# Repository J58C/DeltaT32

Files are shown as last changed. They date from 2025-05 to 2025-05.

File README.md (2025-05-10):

# DeltaT32 – ESP32-C3 Wearable for Capstone



**DeltaT32** is a modular hardware design project based on the **ESP32-C3 Mini-1**, intended primarily for wearable systems, but versatile enough for general-purpose embedded applications. Created using **KiCad 8**, this project includes a main ESP unit and two detachable sensor boards (BMI160/270 and MPU9250), making it ideal for both academic and practical applications.

This design has been created specifically to fulfill the requirements of a **Capstone Project**, integrating modern hardware design practices with real-world applications. Although firmware development is still pending, the hardware is designed to be compatible with the **[esp-rs (ESP32 Rust)](https://github.com/esp-rs)** ecosystem.

## Project Structure

```
DeltaT32/
├── Schematic/ # PDF-format schematics
├── Hardwares/
│ ├── esp-unit-c3-v3/ # KiCad project for the main ESP32-C3 board
│ ├── sensor-bmi-v2/ # KiCad project for the BMI160/270 sensor board
│ └── sensor-mpu-v2/ # KiCad project for the MPU9250 sensor board
├── 3DModels/ # 3D models of components (if available)
├── Archives/ # Archived ZIP files of older versions
├── Materials/ # Bill of Materials (BOM) for each board
└── README.md # Project documentation
````

## Technical Specifications

| Component | Description |
|---|---|
| MCU | ESP32-C3 Mini-1 |
| Sensors | BMI160/270, MPU9250 (modular and detachable) |
| Design Style | Modular: separate mainboard and sensor units |
| CAD Tool | KiCad 8 |
| Firmware | Not included (hardware only) |
| Rust Support | Designed with esp-rs compatibility in mind |
| Outputs | Schematics, BOMs, 3D Visuals |

## Firmware Compatibility

This hardware is designed to be compatible with the **[esp-rs (Rust for ESP32)](https://github.com/esp-rs)** ecosystem, but **no actual firmware has been implemented or tested** using Rust at this time. Custom firmware development in C, C++, or Rust.

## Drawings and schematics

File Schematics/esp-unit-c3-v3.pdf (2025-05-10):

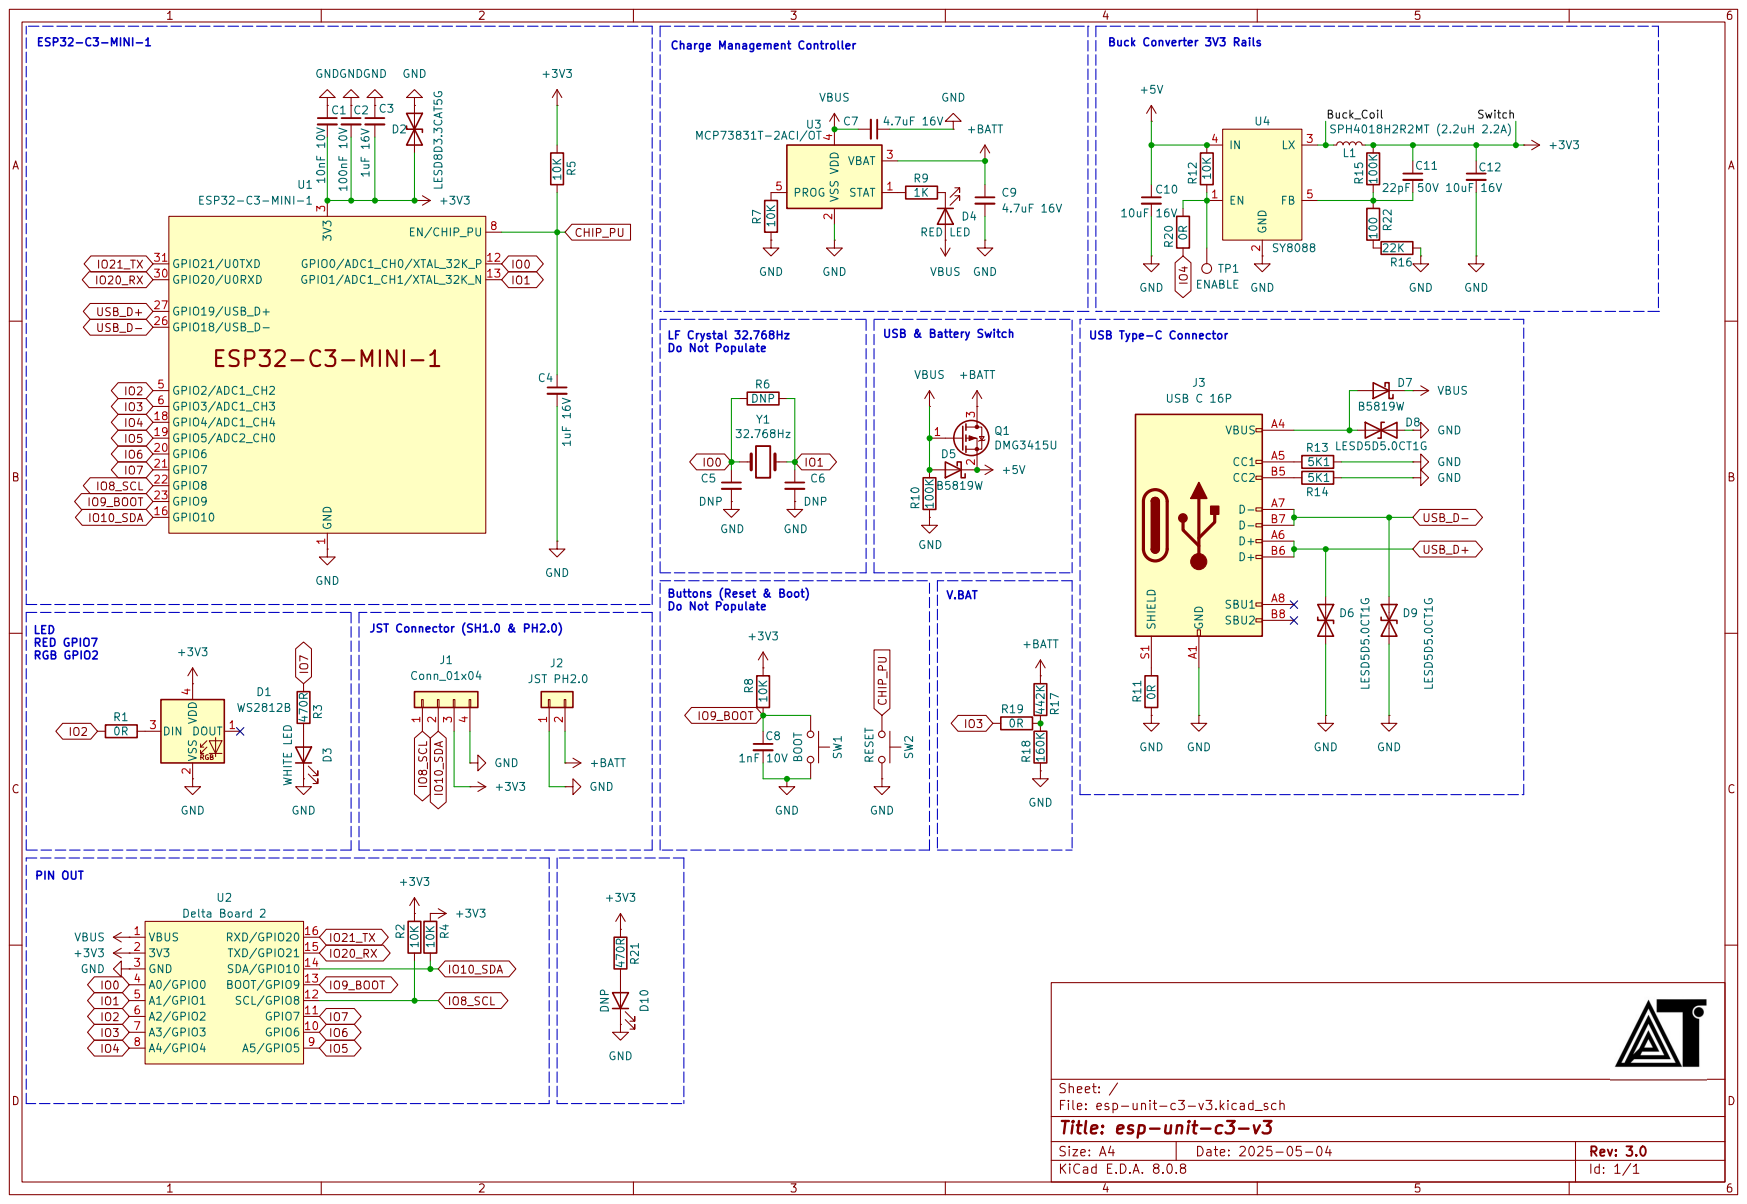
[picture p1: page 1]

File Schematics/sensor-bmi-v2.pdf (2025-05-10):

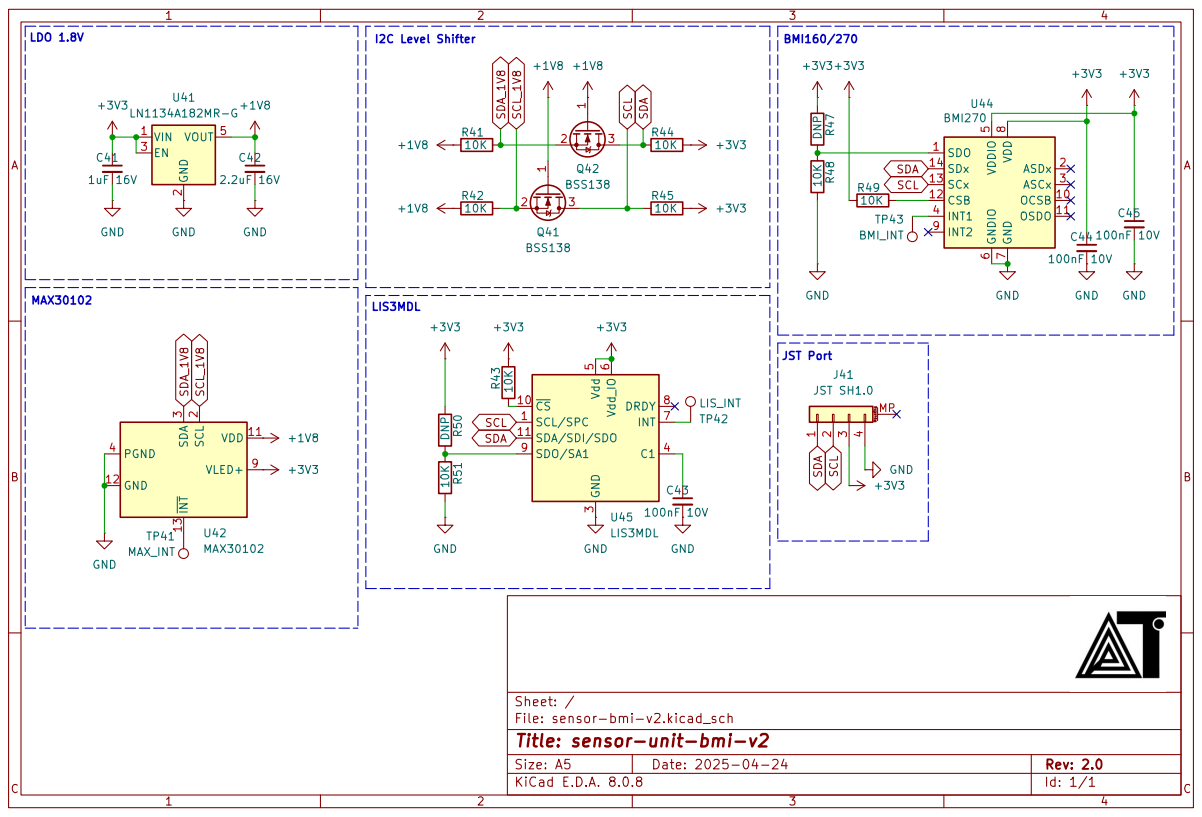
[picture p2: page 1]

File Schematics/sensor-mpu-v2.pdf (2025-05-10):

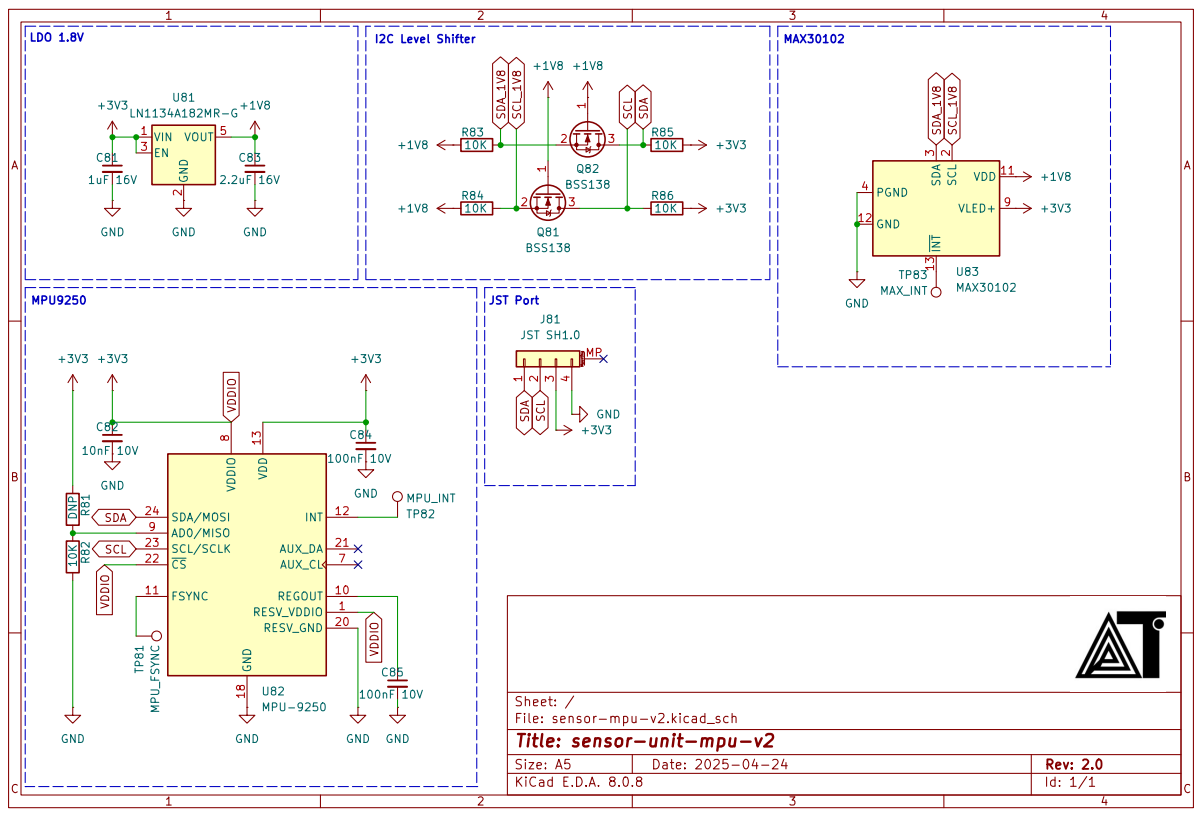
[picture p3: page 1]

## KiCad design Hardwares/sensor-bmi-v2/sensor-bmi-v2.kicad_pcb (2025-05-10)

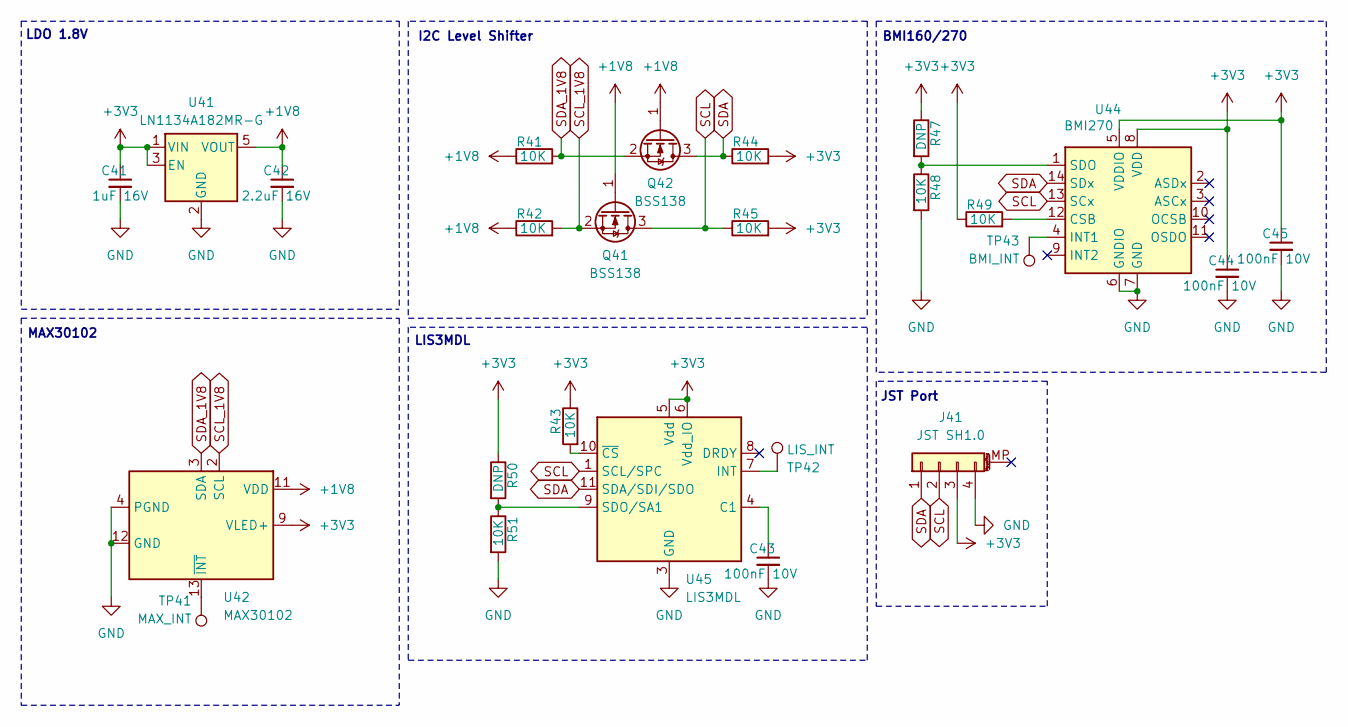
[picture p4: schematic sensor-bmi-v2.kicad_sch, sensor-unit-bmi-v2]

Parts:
C41: 1uF 16V; C_0603_1608Metric; LCSC C15849
C42: 2.2uF 16V; C_0603_1608Metric; LCSC C23630
C43: 100nF 10V; C_0603_1608Metric; LCSC C25744
C44, C45: 100nF 10V; C_0603_1608Metric; LCSC C14663
J41: JST SH1.0; JST_SH_BM04B-SRSS-TB_1x04-1MP_P1.00mm_Vertical
Q41, Q42: BSS138; SOT-23; LCSC C52895
R41, R42, R43, R44, R45, R48, R49, R51: 10K; R_0402_1005Metric; LCSC C25744
R47, R50: DNP; R_0402_1005Metric
TP41: MAX_INT; TestPoint_Pad_D1.0mm
TP42: LIS_INT; TestPoint_Pad_D1.0mm
TP43: BMI_INT; TestPoint_Pad_D1.0mm
U41: LN1134A182MR-G; SOT-23-5; LCSC C141424
U42: MAX30102; Maxim_OLGA-14_3.3x5.6mm_P0.8mm
U44: BMI270; Bosch_LGA-14_3x2.5mm_P0.5mm; LCSC C2836813
U45: LIS3MDL; LGA-12_2x2mm_P0.5mm

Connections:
+1V8: C42.1, Q41.1 (G), Q42.1 (G), R41.1, R42.1, U41.5 (VOUT), U42.11 (VDD)
+3V3: C41.1, C44.1, C45.1, J41.3, R43.1, R44.2, R45.2, R47.1, R49.1, R50.1, U41.1 (VIN), U41.3 (EN), U42.9 (VLED+), U42.10 (VLED+), U44.5 (VDDIO), U44.8 (VDD), U45.5 (Vdd), U45.6 (Vdd_IO)
GND: C41.2, C42.2, C43.2, C44.2, C45.2, J41.4, R48.2, R51.2, U41.2 (GND), U42.4 (PGND), U42.12 (GND), U44.6 (GNDIO), U44.7 (GND), U45.2 (GND), U45.3 (GND), U45.12 (GND)
unnamed: TP41.1, U42.13 (~INT)
unnamed: R49.2, U44.12 (CSB)
unnamed: TP43.1, U44.4 (INT1)
unnamed: R47.2, R48.1, U44.1 (SDO)
unnamed: C43.1, U45.4 (C1)
unnamed: TP42.1, U45.7 (INT)
unnamed: R50.2, R51.1, U45.9 (SDO/SA1)
unnamed: R43.2, U45.10 (~CS)
SCL: J41.2, Q41.3 (D), R45.1, U44.13 (SCx), U45.1 (SCL/SPC)
SCL_1V8: Q41.2 (S), R42.2, U42.2 (SCL)
SDA: J41.1, Q42.3 (D), R44.1, U44.14 (SDx), U45.11 (SDA/SDI/SDO)
SDA_1V8: Q42.2 (S), R41.2, U42.3 (SDA)

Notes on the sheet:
LDO 1.8V
MAX30102
JST Port
LIS3MDL
BMI160/270
I2C Level Shifter

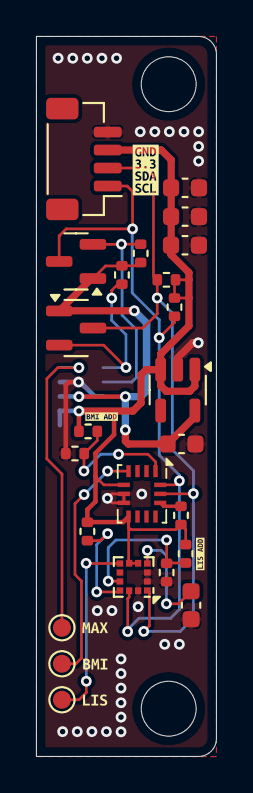
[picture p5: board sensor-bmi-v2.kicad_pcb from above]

Board: 2 copper layers, 10.0 x 40.0 mm, 31 parts (1 on the bottom side), 15 nets.

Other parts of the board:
kibuzzard-680F6A2F: G***; kibuzzard-680F6A2F
kibuzzard-680F6A44: G***; kibuzzard-680F6A44
kibuzzard-680F69F9: G***; kibuzzard-680F69F9
kibuzzard-6818BCEF: G***; kibuzzard-6818BCEF
kibuzzard-6818BD0F: G***; kibuzzard-6818BD0F
kibuzzard-6817376F: G***; kibuzzard-6817376F

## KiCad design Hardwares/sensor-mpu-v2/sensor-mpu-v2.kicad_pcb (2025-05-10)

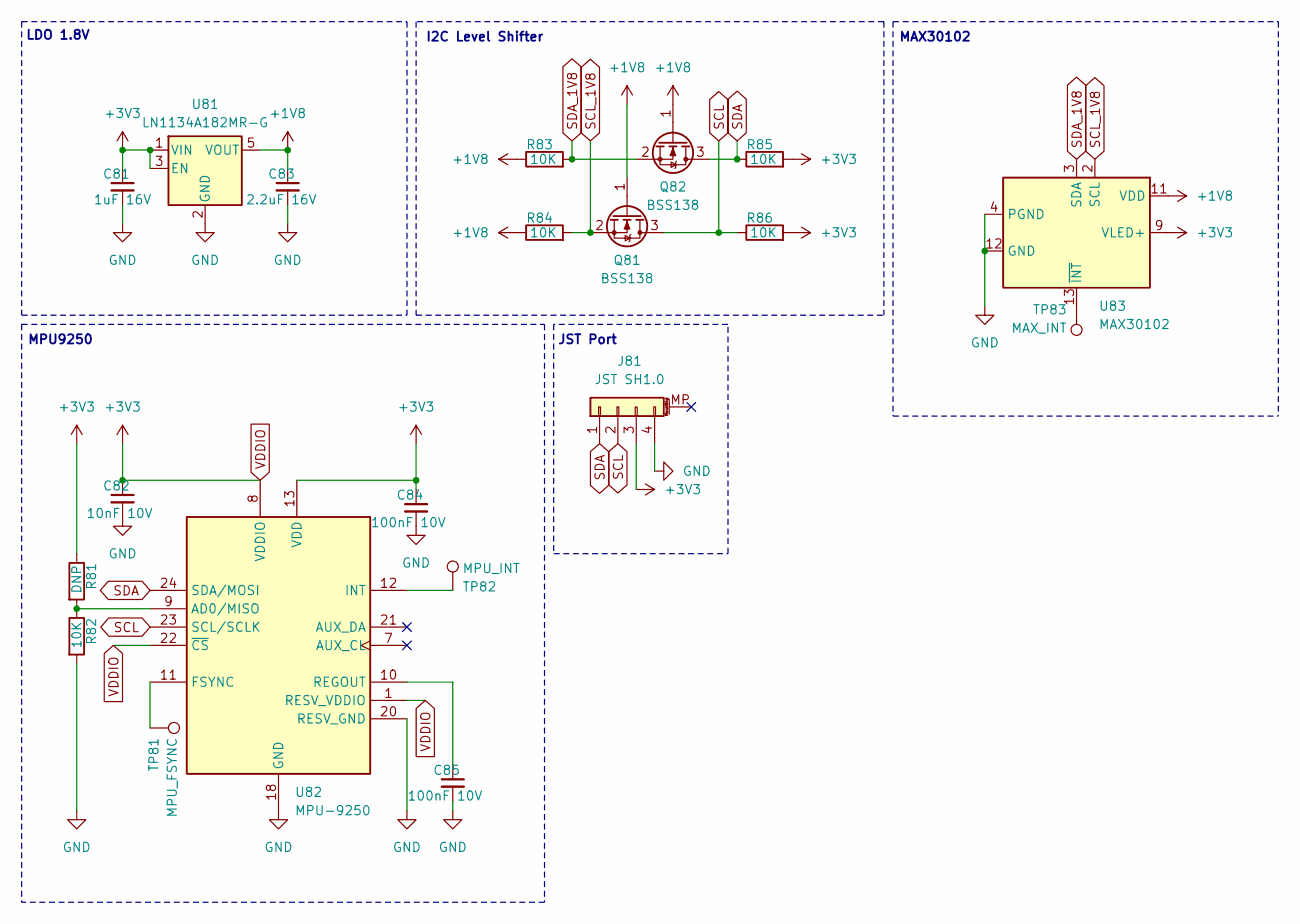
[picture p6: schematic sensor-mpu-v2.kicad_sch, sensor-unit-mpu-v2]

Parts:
C81: 1uF 16V; C_0603_1608Metric; LCSC C52923
C82: 10nF 10V; C_0603_1608Metric; LCSC C15195
C83: 2.2uF 16V; C_0603_1608Metric; LCSC C23630
C84, C85: 100nF 10V; C_0603_1608Metric; LCSC C1525
J81: JST SH1.0; JST_SH_BM04B-SRSS-TB_1x04-1MP_P1.00mm_Vertical
Q81, Q82: BSS138; SOT-23; LCSC C52895
R81: DNP; R_0402_1005Metric
R82, R83, R84, R85, R86: 10K; R_0402_1005Metric; LCSC C25744
TP81: MPU_FSYNC; TestPoint_Pad_D1.0mm
TP82: MPU_INT; TestPoint_Pad_D1.0mm
TP83: MAX_INT; TestPoint_Pad_D1.0mm
U81: LN1134A182MR-G; SOT-23-5; LCSC C141424
U82: MPU-9250; InvenSense_QFN-24_3x3mm_P0.4mm_NoMask
U83: MAX30102; Maxim_OLGA-14_3.3x5.6mm_P0.8mm

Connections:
+1V8: C83.1, Q81.1 (G), Q82.1 (G), R83.1, R84.1, U81.5 (VOUT), U83.11 (VDD)
GND: C81.2, C82.2, C83.2, C84.2, C85.2, J81.4, R82.2, U81.2 (GND), U82.18 (GND), U82.20 (RESV_GND), U83.4 (PGND), U83.12 (GND)
unnamed: R81.2, R82.1, U82.9 (AD0/MISO)
unnamed: TP81.1, U82.11 (FSYNC)
unnamed: TP82.1, U82.12 (INT)
unnamed: C85.1, U82.10 (REGOUT)
unnamed: TP83.1, U83.13 (~INT)
SCL: J81.2, Q81.3 (D), R86.1, U82.23 (SCL/SCLK)
SCL_1V8: Q81.2 (S), R84.2, U83.2 (SCL)
SDA: J81.1, Q82.3 (D), R85.1, U82.24 (SDA/MOSI)
SDA_1V8: Q82.2 (S), R83.2, U83.3 (SDA)
VDDIO: C81.1, C82.1, C84.1, J81.3, R81.1, R85.2, R86.2, U81.1 (VIN), U81.3 (EN), U82.1 (RESV_VDDIO), U82.8 (VDDIO), U82.13 (VDD), U82.22 (~CS), U83.9 (VLED+), U83.10 (VLED+)

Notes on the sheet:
I2C Level Shifter
MPU9250
MAX30102
JST Port
LDO 1.8V

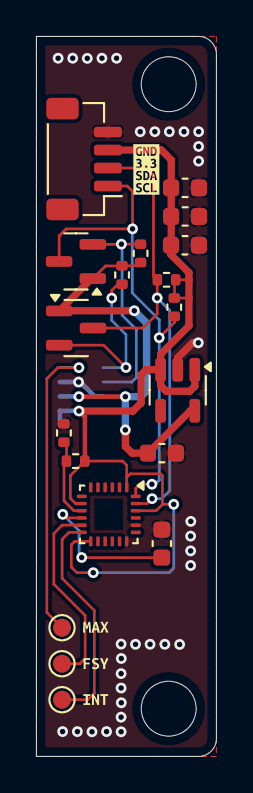
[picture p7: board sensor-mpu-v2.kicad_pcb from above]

Board: 2 copper layers, 10.0 x 40.0 mm, 24 parts (1 on the bottom side), 12 nets.

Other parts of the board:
kibuzzard-680F6A44: G***; kibuzzard-680F6A44
kibuzzard-6817376F: G***; kibuzzard-6817376F
kibuzzard-6817407C: G***; kibuzzard-6817407C
kibuzzard-68174073: G***; kibuzzard-68174073

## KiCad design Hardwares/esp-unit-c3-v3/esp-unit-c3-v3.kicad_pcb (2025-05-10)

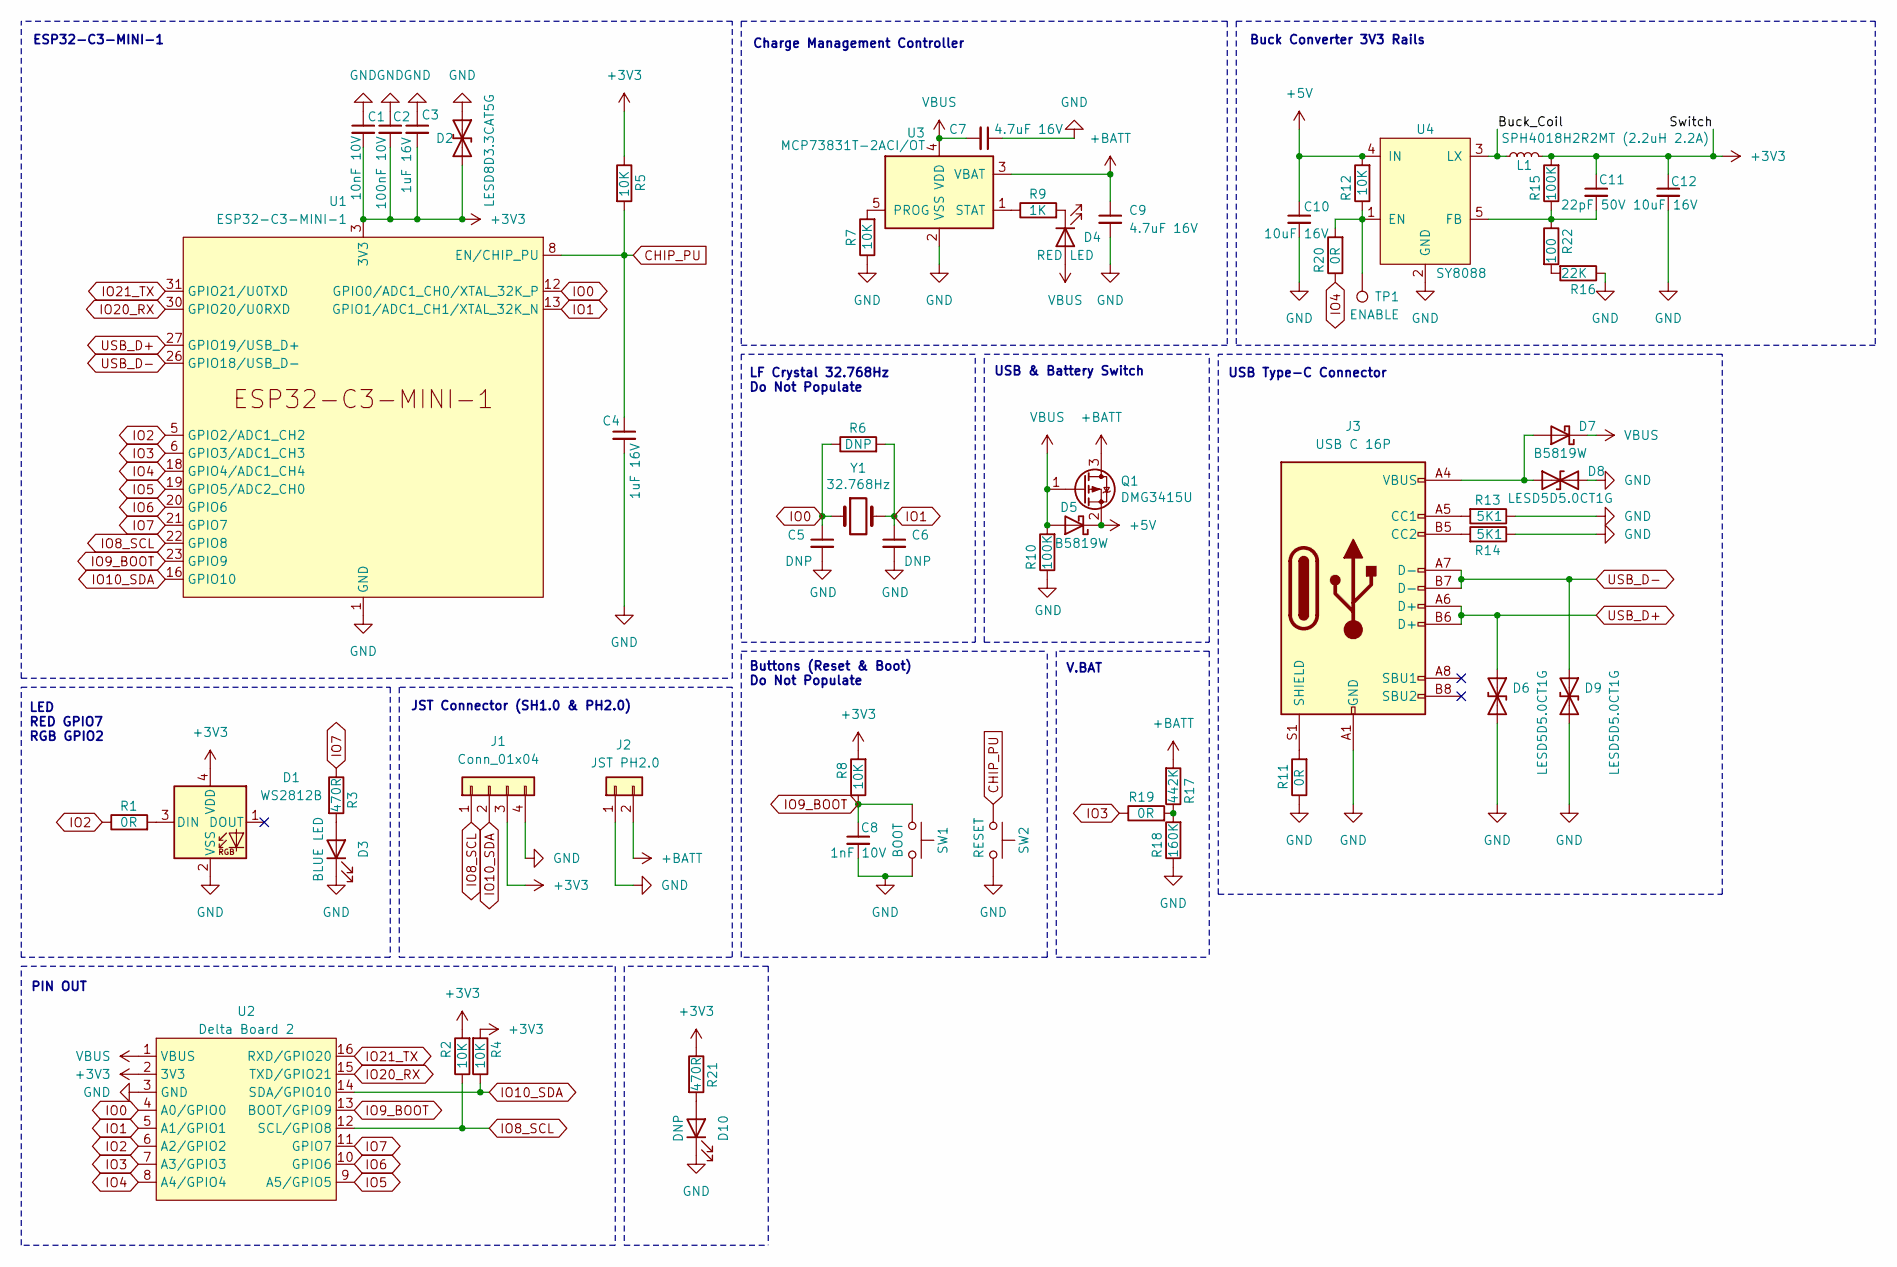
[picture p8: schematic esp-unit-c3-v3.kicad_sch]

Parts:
C1: 10nF 10V; C_0402_1005Metric; LCSC C15195
C2: 100nF 10V; C_0402_1005Metric; LCSC C1525
C3, C4: 1uF 16V; C_0402_1005Metric; LCSC C52923
C5, C6: DNP; C_0402_1005Metric
C7, C9: 4.7uF 16V; C_0603_1608Metric; LCSC C19666
C8: 1nF 10V; C_0402_1005Metric; LCSC C1523
C10, C12: 10uF 16V; C_0805_2012Metric; LCSC C15850
C11: 22pF 50V; C_0603_1608Metric; LCSC C1653
D1: WS2812B; LED_WS2812B-2020_PLCC4_2.0x2.0mm; LCSC C965555
D2: LESD8D3.3CAT5G; D_SOD-882; LCSC C172409
D3: BLUE LED; LED_0603_1608Metric; LCSC C2288
D4: RED LED; LED_0603_1608Metric; LCSC C2286
D5, D7: B5819W; D_SOD-123; LCSC C8598
D6, D8, D9: LESD5D5.0CT1G; D_SOD-523; LCSC C383211
D10: DNP; LED_0603_1608Metric; LCSC C2288
J1: Conn_01x04; PinHeader_1x04_P1.00mm_Vertical
J2: JST PH2.0; JST_PH2.0
J3: USB C 16P; USB_C_Receptacle_GCT_USB4105-xx-A_16P_TopMnt_Horizontal; PARTREV A3; LCSC C165948
L1: SPH4018H2R2MT (2.2uH 2.2A); L_Bourns-SRN4018; LCSC C370436
Q1: DMG3415U; SOT-23; LCSC C96616
R1, R11, R19, R20: 0R; R_0402_1005Metric; LCSC C17168
R2, R4, R5, R7, R8, R12: 10K; R_0402_1005Metric; LCSC C25744
R3, R21: 470R; R_0402_1005Metric; LCSC C25117
R6: DNP; R_0402_1005Metric
R9: 1K; R_0402_1005Metric; LCSC C11702
R10, R15: 100K; R_0402_1005Metric; LCSC C25741
R13, R14: 5K1; R_0402_1005Metric; LCSC C25905
R16: 22K; R_0402_1005Metric; LCSC C25768
R17: 442K; R_0805_2012Metric; LCSC C17699
R18: 160K; R_0805_2012Metric; LCSC C17485
R22: 100; R_0402_1005Metric; LCSC C25076
SW1: BOOT; SW_Push_SPST_NO_Alps_SKRK
SW2: RESET; SW_Push_SPST_NO_Alps_SKRK
TP1: ENABLE; TestPoint_Pad_D1.0mm
U1: ESP32-C3-MINI-1; LCSC C2838502
U2: Delta Board 2; Delta_Board-2
U3: MCP73831T-2ACI/OT; SOT-23-5; LCSC C424093
U4: SY8088; SOT-23-5; LCSC C479072
Y1: 32.768Hz; Crystal_SMD_3215-2Pin_3.2x1.5mm

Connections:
+3V3: C1.2, C2.2, C3.2, C11.1, C12.1, D1.4 (VDD), D2.2 (A2), J1.3, L1.2, R2.2, R4.2, R5.1, R8.2, R15.2, R21.1, U1.3 (3V3), U2.2 (3V3)
+5V: C10.1, D5.1 (K), Q1.2 (S), R12.2, U4.4 (IN)
+BATT: C9.1, J2.2, Q1.3 (D), R17.2, U3.3 (VBAT)
/Buck_Coil: L1.1, U4.3 (LX)
CHIP_PU: C4.1, R5.2, SW2.1, U1.8 (EN/CHIP_PU)
GND: C1.1, C2.1, C3.1, C4.2, C5.2, C6.2, C7.1, C8.2, C9.2, C10.2, C12.2, D1.2 (VSS), D2.1 (A1), D3.1 (K), D6.2 (A2), D8.2 (A2), D9.2 (A2), D10.1 (K), J1.4, J2.1, J3.A1 (GND), J3.A12 (GND), J3.B1 (GND), J3.B12 (GND), R7.1, R10.1, R11.1, R13.1, R14.1, R16.1, R18.1, SW1.2, SW2.2, U1.1 (GND), U1.2 (GND), U1.11 (GND), U1.14 (GND), U1.36 (GND), U1.37 (GND), U1.38 (GND), U1.39 (GND), U1.40 (GND), U1.41 (GND), U1.42 (GND), U1.43 (GND), U1.44 (GND), U1.45 (GND), U1.46 (GND), U1.47 (GND), U1.48 (GND), U1.49 (GND), U1.50 (GND), U1.51 (GND), U1.52 (GND), U1.53 (GND), U2.3 (GND), U3.2 (VSS), U4.2 (GND)
IO0: C5.1, R6.1, U1.12 (GPIO0/ADC1_CH0/XTAL_32K_P), U2.4 (A0/GPIO0), Y1.1
IO1: C6.1, R6.2, U1.13 (GPIO1/ADC1_CH1/XTAL_32K_N), U2.5 (A1/GPIO1), Y1.2
IO2: R1.1, U1.5 (GPIO2/ADC1_CH2), U2.6 (A2/GPIO2)
IO3: R19.1, U1.6 (GPIO3/ADC1_CH3), U2.7 (A3/GPIO3)
IO4: R20.1, U1.18 (GPIO4/ADC1_CH4), U2.8 (A4/GPIO4)
IO5: U1.19 (GPIO5/ADC2_CH0), U2.9 (A5/GPIO5)
IO6: U1.20 (GPIO6), U2.10 (GPIO6)
IO7: R3.1, U1.21 (GPIO7), U2.11 (GPIO7)
IO8_SCL: J1.1, R2.1, U1.22 (GPIO8), U2.12 (SCL/GPIO8)
IO9_BOOT: C8.1, R8.1, SW1.1, U1.23 (GPIO9), U2.13 (BOOT/GPIO9)
IO10_SDA: J1.2, R4.1, U1.16 (GPIO10), U2.14 (SDA/GPIO10)
IO20_RX: U1.30 (GPIO20/U0RXD), U2.15 (TXD/GPIO21)
IO21_TX: U1.31 (GPIO21/U0TXD), U2.16 (RXD/GPIO20)
unnamed: D1.3 (DIN), R1.2
unnamed: D3.2 (A), R3.2
unnamed: D4.1 (K), R9.2
unnamed: D7.2 (A), D8.1 (A1), J3.A4 (VBUS), J3.A9 (VBUS), J3.B4 (VBUS), J3.B9 (VBUS)
unnamed: D10.2 (A), R21.2
unnamed: J3.A5 (CC1), R13.2
unnamed: J3.B5 (CC2), R14.2
unnamed: J3.S1 (SHIELD), R11.2
unnamed: R16.2, R22.2
unnamed: R17.1, R18.2, R19.2
unnamed: R7.2, U3.5 (PROG)
unnamed: R9.1, U3.1 (STAT)
unnamed: R12.1, R20.2, TP1.1, U4.1 (EN)
unnamed: C11.2, R15.1, R22.1, U4.5 (FB)
USB_D+: D6.1 (A1), J3.A6 (D+), J3.B6 (D+), U1.27 (GPIO19/USB_D+)
USB_D-: D9.1 (A1), J3.A7 (D-), J3.B7 (D-), U1.26 (GPIO18/USB_D-)
VBUS: C7.2, D4.2 (A), D5.2 (A), D7.1 (K), Q1.1 (G), R10.2, U2.1 (VBUS), U3.4 (VDD)

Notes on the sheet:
LED RED GPIO7 RGB GPIO2
LF Crystal 32.768Hz Do Not Populate
JST Connector (SH1.0 & PH2.0)
Charge Management Controller
PIN OUT
Buck Converter 3V3 Rails
USB & Battery Switch
Buttons (Reset & Boot) Do Not Populate
V.BAT
USB Type-C Connector
ESP32-C3-MINI-1

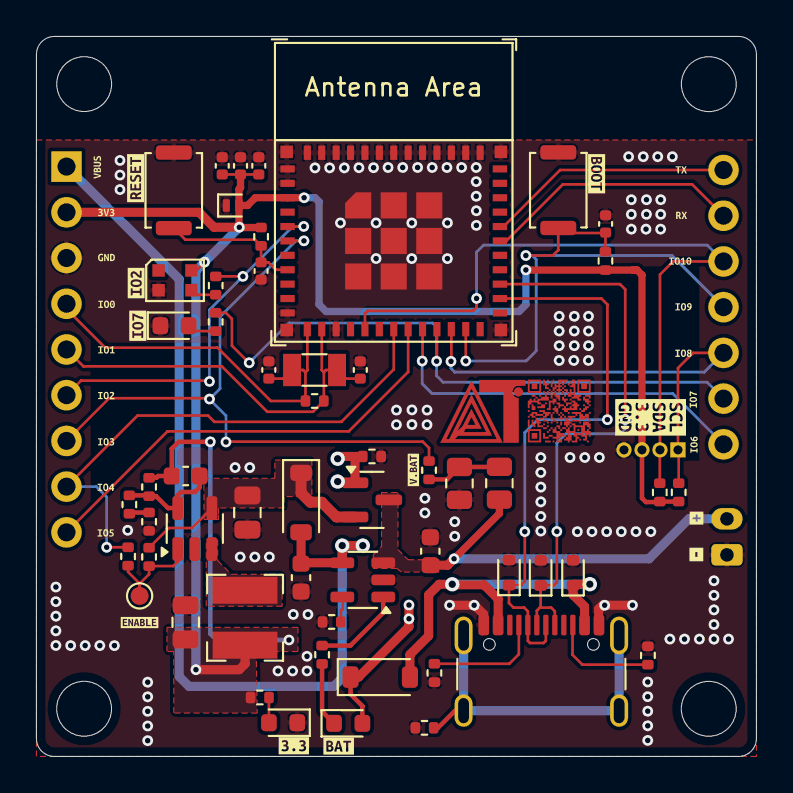
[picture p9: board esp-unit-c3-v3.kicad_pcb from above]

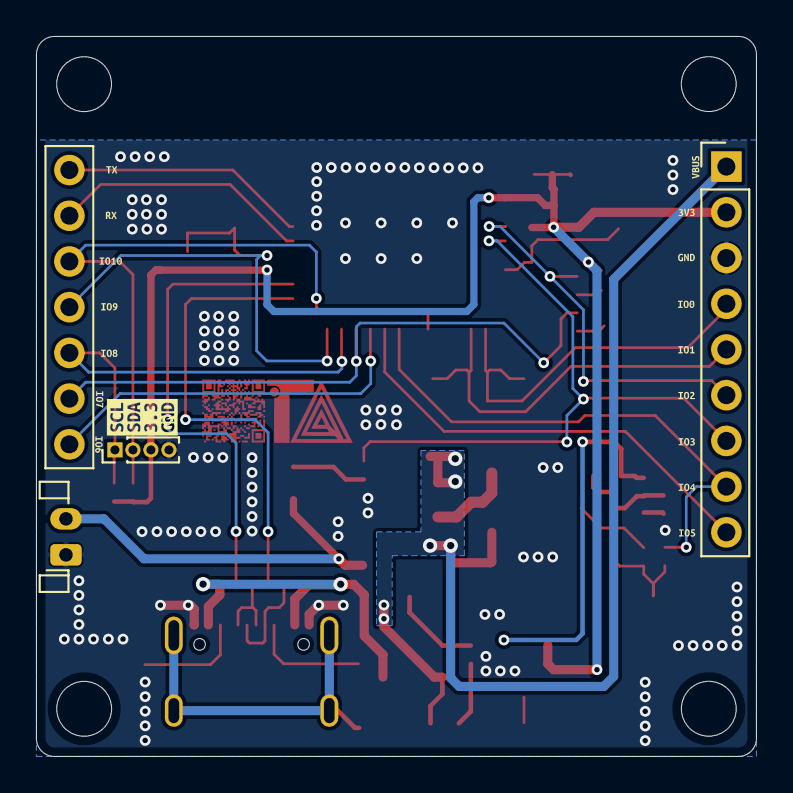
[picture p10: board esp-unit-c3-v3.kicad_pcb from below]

Board: 2 copper layers, 40.0 x 40.0 mm, 101 parts (19 on the bottom side), 36 nets.

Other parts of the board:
kibuzzard-680CD9B9: G***; kibuzzard-680CD9B9
kibuzzard-680CD9CB: G***; kibuzzard-680CD9CB
kibuzzard-680CDA1E: G***; kibuzzard-680CDA1E
kibuzzard-680CDA08: G***; kibuzzard-680CDA08
kibuzzard-680CDA64: G***; kibuzzard-680CDA64
kibuzzard-680CDBCC: G***; kibuzzard-680CDBCC
kibuzzard-680CDBED: G***; kibuzzard-680CDBED
kibuzzard-680CDFA2: G***; kibuzzard-680CDFA2
kibuzzard-680CFCF0, kibuzzard-680CFCF0#2: G***; kibuzzard-680CFCF0
kibuzzard-680CFD7F, kibuzzard-680CFD7F#2: G***; kibuzzard-680CFD7F
kibuzzard-680CFD12, kibuzzard-680CFD12#2: G***; kibuzzard-680CFD12
kibuzzard-680CFD73, kibuzzard-680CFD73#2: G***; kibuzzard-680CFD73
kibuzzard-680CFDA8, kibuzzard-680CFDA8#2: G***; kibuzzard-680CFDA8
kibuzzard-680CFDBB, kibuzzard-680CFDBB#2: G***; kibuzzard-680CFDBB
kibuzzard-680CFDCF, kibuzzard-680CFDCF#2: G***; kibuzzard-680CFDCF
kibuzzard-680CFDE4, kibuzzard-680CFDE4#2: G***; kibuzzard-680CFDE4
kibuzzard-680CFDFB, kibuzzard-680CFDFB#2: G***; kibuzzard-680CFDFB
kibuzzard-680CFE08, kibuzzard-680CFE08#2: G***; kibuzzard-680CFE08
kibuzzard-680CFF32: G***; kibuzzard-680CFF32
kibuzzard-6816DD82, kibuzzard-6816DD82#2: G***; kibuzzard-6816DD82
kibuzzard-6816DDEA, kibuzzard-6816DDEA#2: G***; kibuzzard-6816DDEA
kibuzzard-6816DDFD, kibuzzard-6816DDFD#2: G***; kibuzzard-6816DDFD
kibuzzard-6816DE5B, kibuzzard-6816DE5B#2: G***; kibuzzard-6816DE5B
kibuzzard-6816DE78, kibuzzard-6816DE78#2: G***; kibuzzard-6816DE78
kibuzzard-6816DE97, kibuzzard-6816DE97#2: G***; kibuzzard-6816DE97
kibuzzard-6816EC1C, kibuzzard-6816EC1C#2: G***; kibuzzard-6816EC1C
kibuzzard-68198D94: G***; kibuzzard-68198D94

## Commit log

2025-01-27 Non Latch
    [Caps32Project.kicad_pcb, Caps32Project.kicad_sch]
2025-01-29 Update and rename pcb.yaml to images.yaml
2025-01-29 Update and rename images.yaml to PCB42.yaml
2025-01-29 Update and rename PCB42.yaml to images.yaml
2025-01-29 Update PCB render images for branch 17048
2025-01-29 Sync from 42 to main/42
    [Caps32Project.kicad_pcb, Caps32Project.kicad_sch]
2025-01-29 Sync from 17048 to main/17048
    [Caps32Project.kicad_pcb, Caps32Project.kicad_sch]
2025-01-29 Sync from 340 to main/340
    [Caps32Project.kicad_pcb, Caps32Project.kicad_sch]
2025-01-30 Move PCB render images from branch 42 to Images/42
2025-01-30 Move PCB render images from branch 42 to Images/42 and remove old images
2025-04-08 Update Test
    [DeltaT32.kicad_pcb, DeltaT32.kicad_sch]
2025-04-08 Up
    Upgrade kicad version
    [DeltaT32.kicad_pcb, DeltaT32.kicad_sch]
2025-04-08 Update PCB render images for main
2025-04-10 Update Board
    [BMI.kicad_sch, DeltaT32.kicad_pcb, DeltaT32.kicad_sch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]
2025-04-26 Downgrade and pcb breakdown
    [DeltaT32.kicad_pcb, esp-unit-c3-v1.kicad_pcb, esp-unit-c3-v1.kicad_sch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]
2025-04-28 add sensor board
    [esp-unit-c3-v2.kicad_pcb, esp-unit-c3-v2.kicad_sch, sensor-bmi.kicad_pcb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]
2025-04-29 panelize sensor board
    [sensor-bmi.kicad_pcb, sensor-mpu.kicad_pcb]
2025-05-04 Merge pull request #4 from J58C/010525
    010525
    [esp-unit-c3-v1.kicad_pcb, esp-unit-c3-v1.kicad_sch, esp-unit-c3-v2.kicad_pcb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]
2025-05-10 Update for poduction
    [esp-unit-c3-v2.kicad_pcb, esp-unit-c3-v2.kicad_sch, esp-unit-c3-v3.kicad_pcb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]
2025-05-10 adjustable repo
    [esp-unit-c3-v3.kicad_pcb, esp-unit-c3-v3.kicad_sch, sensor-bmi-v2.kicad_pcb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]

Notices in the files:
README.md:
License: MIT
